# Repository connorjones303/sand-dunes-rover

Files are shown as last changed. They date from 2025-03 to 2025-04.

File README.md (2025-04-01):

# Sand Dunes Rover Project

Spring 2025
Arapahoe Community College Robotics Club - rover project

## Overview

This project implements a rover system designed for sand dune environments. The system consists of:

1. An Arduino-controlled **Rover** with DC motors, servo steering, IMU sensors, and LIDAR
2. A Raspberry Pi **Controller** that interfaces with sensors and communicates with the Arduino

## System Architecture

### Rover Hardware

The rover consists of:

- Arduino controller with SoftPWM for motor control
- 2 DC motor channels for differential drive
- 2 Servo channels for wheel steering
- I2C bus for sensor communication

### Sensor System

The sensor system includes:

- MPU6050 IMU (Accelerometer/Gyroscope) connected via I2C
- LIDAR sensor connected via serial port for distance measurement
- UART connection between Raspberry Pi and Arduino for commands

## Features

- **Movement Control**: Forward, backward, left, right, stop, and active braking
- **Precision Steering**: Servo-controlled wheel direction with configurable angles
- **IMU Data**: Real-time acceleration and gyroscope data collection
- **Motion Detection**: Algorithms to detect significant movement changes
- **LIDAR Scanning**: Collects distance measurements across 360° rotation
- **Data Processing**: Converts LIDAR polar coordinates to Cartesian
- **Data Logging**: Records LIDAR measurements to timestamped files

## Control System

### Arduino Motor Control

- **DC Motor States**:
  - Forward: IN1=HIGH, IN2=LOW
  - Reverse: IN1=LOW, IN2=HIGH
  - Brake: IN1=HIGH, IN2=HIGH
  - Coast: IN1=LOW, IN2=LOW

- **Servo Control**:
  - Straight position: 45 degrees (configurable)
  - Turn margin: 45 degrees (configurable)

### Command Interface

The rover accepts the following UART commands:

- **f**: Move forward
- **b**: Move backward
- **l**: Turn left
- **r**: Turn right
- **s**: Stop motors (coast)
- **t**: Brake motors (active stop)
- **w**: Start writing LIDAR data
- **e**: End writing LIDAR data
- **q**: Quit controller program

## Sensor Details

### MPU6050 IMU Sensor

- Measures acceleration and angular velocity in 3 axes
- Detects movement with configurable thresholds
- Provides data in physical units (g for acceleration, degrees/s for rotation)

### LIDAR Sensor

- Rotational scanner providing 360° distance measurements
- Data provided in polar format (angle, distance, intensity)
- Converts to Cartesian coordinates (x, y)
- Outputs timestamped data for analysis and mapping

## Data Format

### IMU Data Format

```
Accel (g): X=0.00, Y=0.00, Z=0.00 | Gyro (deg/s): X=0.00, Y=0.00, Z=0.00
```
### LIDAR Data Format
```
timestamp,angle,distance,intensity,x,y
1711212151.324,352.45,342,127,328.4,-95.2
```
## Getting Started

### Prerequisites

- Arduino with SoftPWM, Servo, and SoftI2CMaster libraries
- Raspberry Pi with Python 3
- Required Python packages:
  - serial
  - smbus
  - time
  - struct
  - math
  - os
  - datetime

### Hardware Setup

1. Connect Arduino to Raspberry Pi via UART (/dev/ttyACM0)
2. Connect MPU6050 to I2C bus 1
3. Connect LIDAR to serial port (/dev/ttyUSB0)
4. Connect motors and servos as defined in the pin assignments

### Running the Controller

1. Power on the rover hardware
2. Run the Python controller script
3. Enter commands via the terminal interface

## Troubleshooting

### IMU Issues
- Check I2C bus connections
- Verify the IMU address (default: 0x68)
- Use scan_bus() function to detect connected I2C devices

### LIDAR Issues
- Verify serial port connection (/dev/ttyUSB0)
- Ensure baudrate is set to 230400
- Check data format with debug output

### Motor Control Issues
- Verify the Arduino is properly responding to commands
- Check motor driver connections
- Verify servo positions and calibration

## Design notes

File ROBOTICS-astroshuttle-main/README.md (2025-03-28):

# ROBOTICS-astroshuttle

**COSGC ROBOTICS CHALLENGE 2024-2025**  
**TEAM AXIOM @ ARAPAHOE COMMUNITY COLLEGE**  
**ROVR: Oberon**  
**DANIEL KRONEBERGER**

---

## Table of Contents

- [Project Overview](#project-overview)
- [Hardware Components](#hardware-components)
- [Software Components](#software-components)
- [Ultrasonic Navigation System](#ultrasonic-navigation-system)
- [LiDAR System](#lidar-system)
- [Navigation and Control](#navigation-and-control)

---

## Project Overview

**ROVR: Oberon** is an autonomously navigating Martian rover developed for the COSGC Robotics Challenge 2024-2025. Developed with TEAM AXIOM @ ACC.

---

## Hardware Components

- **Motors:**  
  - 4× 25mm gear motors (without encoders)  
  - 2× 20mm gear motors (without encoders)

- **Motor Drivers:**  
  - L298N or BTS7960 motor controllers (depending on availability and performance requirements)

- **Arduino:**  
  - Receives serial commands from the Raspberry Pi and translates them into PWM signals for the motor drivers.  
  - Also manages servo control for steering.

- **Raspberry Pi:**  
  - Runs Ubuntu 22.04 with ROS 2 Humble.  
  - Hosts SLAM and navigation nodes as well as a custom Python command hub that communicates with the Arduino.

- **LD19 LiDAR Module:**  
  - Provides 2D scan data on the `/scan` topic for SLAM mapping and localization.

- **Ultrasonic Sensors:**  
  - Mounted near the wheels, these provide real-time distance measurements to assist in obstacle avoidance and fine navigation adjustments.

- **Additional Components:**  
  - Wiring, power supplies (including boost converters), mounting hardware, and other electronics needed to integrate the system into a mobile robotic platform.

---

## Software Components

- **ROS 2 Humble on Ubuntu 22.04**  
  - Serves as the core middleware for robotic communication and process management.

- **slam_toolbox**  
  - Performs real-time SLAM for mapping and localization in either mapping or localization mode.

- **Nav2 (Navigation 2)**  
  - Plans paths and generates velocity commands on the `/cmd_vel` topic based on user-defined navigation goals.

- **Custom Serial Bridge Node**  
  - Converts ROS velocity commands into serial commands for the Arduino.

- **Arduino Firmware**  
  - Processes a universal serial command protocol to execute commands like `driveF`, `pivotL`, `skidL`, etc.  
  - Controls motors and servos based on these commands.

- **Python Navigation Scripts**  
  - Run on the Raspberry Pi to collect ultrasonic sensor data and autonomously decide optimal navigation commands.  
  - Examples include routines for forward motion followed by pivot scanning to find the best clearance.

---

## Ultrasonic Navigation System

The ultrasonic system enhances local navigation by providing real-time distance measurements:

- **Sensor Setup:**  
  - Two HC-SR04 (or similar) ultrasonic sensors are mounted on the left and right sides of the rover.  
  - Each sensor uses a TRIG and an ECHO pin connected to the Raspberry Pi’s GPIO.

- **Operation:**  
  - The Python script periodically triggers each sensor, calculates the distance based on the echo pulse duration, and evaluates the clearance on both sides.  
  - When the rover is in motion, if either sensor detects an obstacle (or if the combined distance is below a defined threshold), the system initiates a pivot routine.

- **Pivot Routine:**  
  - The rover first drives forward for a preset duration.  
  - It then sequentially pivots left and right (straightening the wheels between movements) to measure the distances at several small angles.  
  - The angle with the greatest combined distance from both sensors is chosen as the optimal heading.  
  - If the distances remain below a threshold, the rover will pivot further to try to clear the obstacle before resuming forward motion.

---

## LiDAR System

The LiDAR system provides a higher-level view of the environment for mapping and navigation:

1. **Mapping Phase:**  
   - The LD19 LiDAR publishes scan data to the `/scan` topic.  
   - `slam_toolbox` processes these scans to generate a 2D map in real time.  
   - The map is visualized in RViz, allowing for immediate feedback during the mapping process.  
   - Once a satisfactory map is generated, it can be saved using the `/slam_toolbox/save_map` service.

2. **Navigation Phase:**  
   - The system is reconfigured to run `slam_toolbox` in localization mode using the saved map.  
   - A navigation goal is set in RViz via the “2D Nav Goal” tool.  
   - Nav2 computes a global path and publishes local velocity commands to `/cmd_vel`.

3. **Motion Execution:**  
   - A custom Serial Bridge Node converts `/cmd_vel` commands into serial commands (such as `driveF` or `pivotL`) that are sent to the Arduino.  
   - The Arduino executes these commands, controlling the motors and servos to move the rover along the planned path.

4. **Optional Odometry Bridge:**  
   - In the absence of wheel encoders, a dummy odometry publisher creates an `/odom` topic from the LiDAR-based pose estimate, ensuring compatibility with Nav2’s requirements.

---

## Navigation and Control

The rover’s navigation system is a combination of high-level planning and low-level sensor-based adjustments:

- **Universal Serial Command Protocol:**  
  A standard set of commands has been defined to control the rover’s movements:

  - `skidL` – skid steer left (in-place turn) [DC only]  
  - `skidR` – skid steer right (in-place turn) [DC only]  
  - `driveF` – drive forward  
  - `driveB` – drive backward  
  - `driveL` – servo-assisted turn left (no differential drive)  
  - `driveR` – servo-assisted turn right (no differential drive)  
  - `DdriveL` – servo-assisted turn left (with slight differential drive)  
  - `DriveR` – servo-assisted turn right (with slight differential drive)  
  - `pivotL` – turns servos into a circle and skids left  
  - `pivotR` – turns servos into a circle and skids right  
  - `steerL` – servo ONLY turn left (no drive)  
  - `steerR` – servo ONLY turn right (no drive)  
  - `steerZ` – zero the servos  
  - `S` – stop motors  
  - `C` – show commands

- **Raspberry Pi Command Hub:**  
  - A Python application running on the Pi communicates with the Arduino over serial.  
  - It reads ultrasonic sensor data via the GPIO pins.  
  - Based on sensor input, it determines whether to drive forward or perform a pivot scan.  
  - The system tests multiple pivot angles (with wheel straightening between each pivot) and selects the angle that yields the maximum clearance.  
  - The chosen command is then sent to the Arduino to execute the movement.

---

*For any questions or contributions, please contact Daniel Kroneberger or open an issue on this repository.*

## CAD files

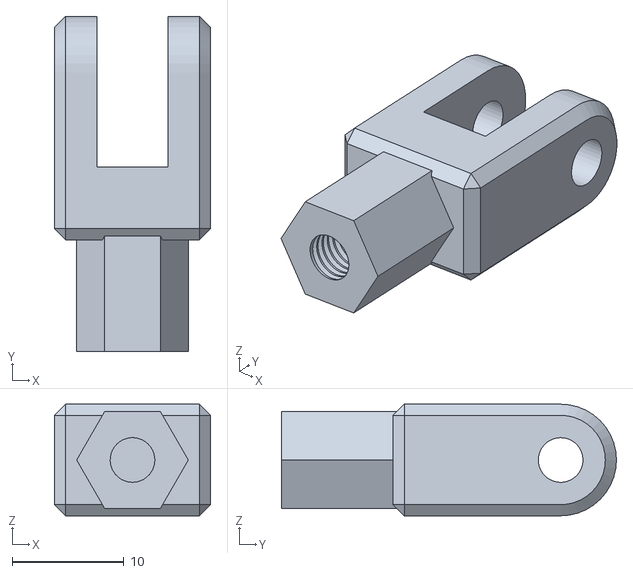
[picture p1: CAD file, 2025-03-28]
ROBOTICS-astroshuttle-main/STLs-astroshuttle/BLUEpart-astroshuttle.STL
14.0 x 30.0 x 10.0

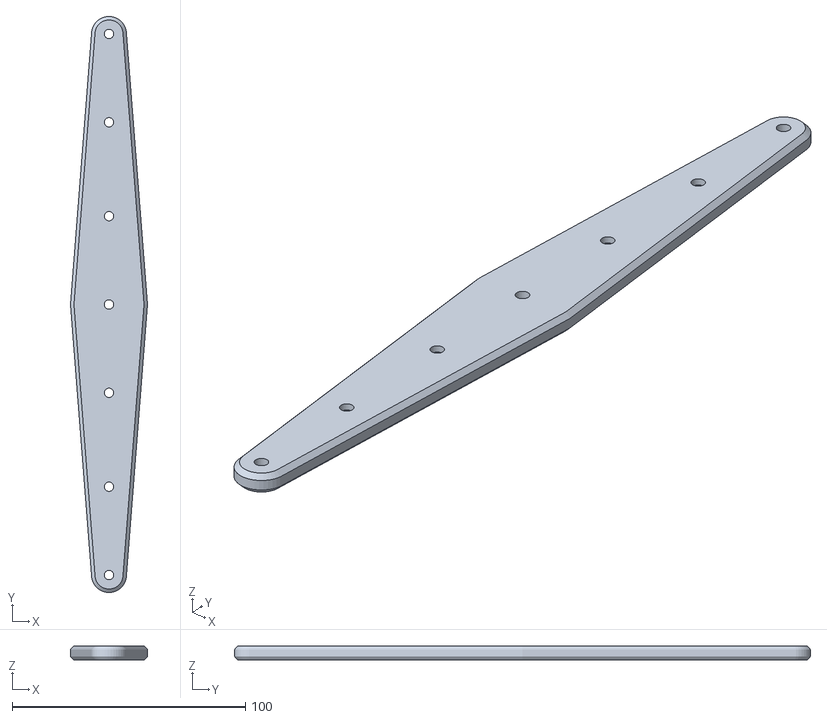
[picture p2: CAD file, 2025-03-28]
ROBOTICS-astroshuttle-main/STLs-astroshuttle/purplebar-astroshuttle.STL
33.0 x 247.0 x 6.00

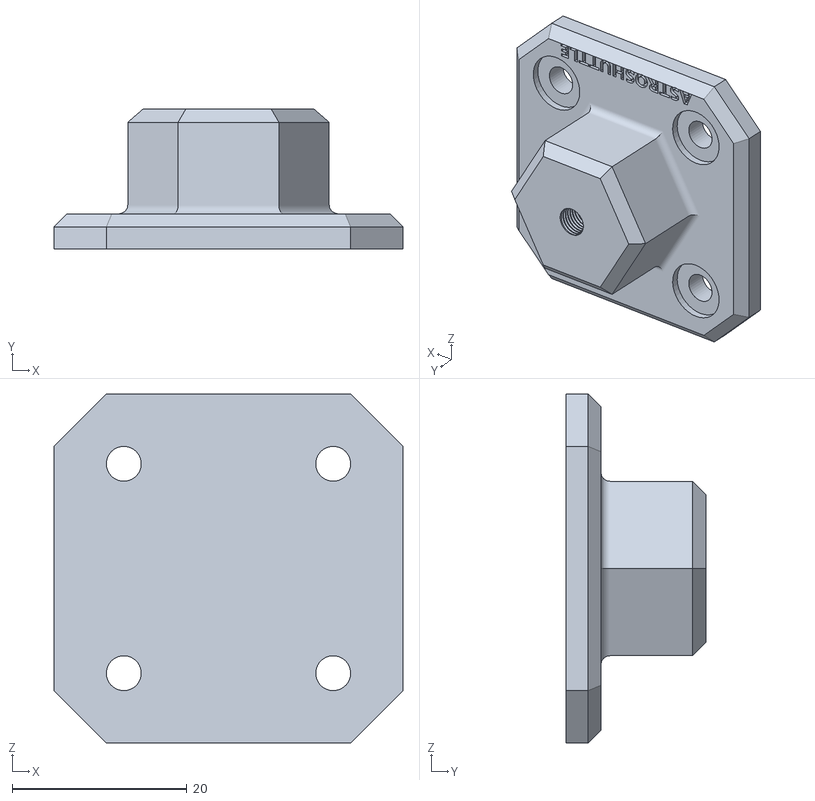
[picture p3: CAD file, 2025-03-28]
ROBOTICS-astroshuttle-main/STLs-astroshuttle/REDpartEVEN-astroshuttle.STL
40.0 x 16.0 x 40.0

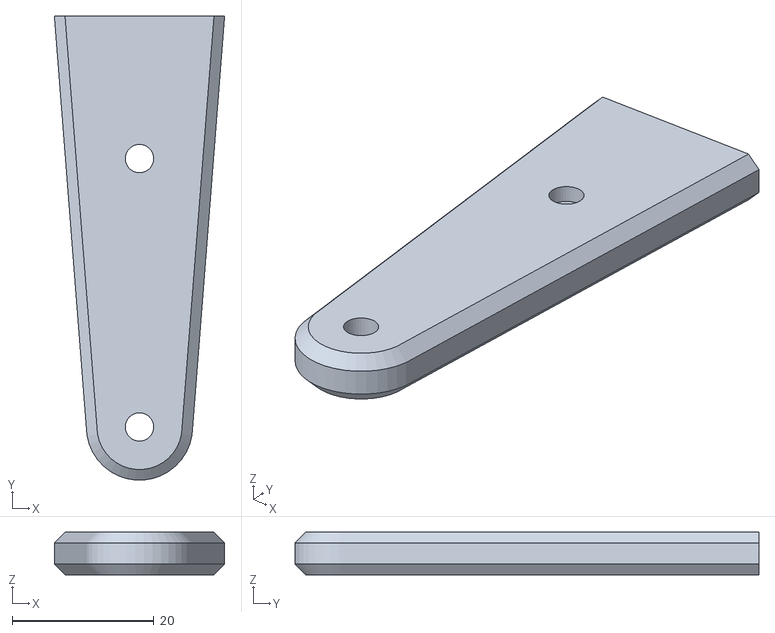
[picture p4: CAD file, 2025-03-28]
ROBOTICS-astroshuttle-main/STLs-astroshuttle/purplebar-edge-astroshuttle.STL
24.0 x 65.5 x 6.00

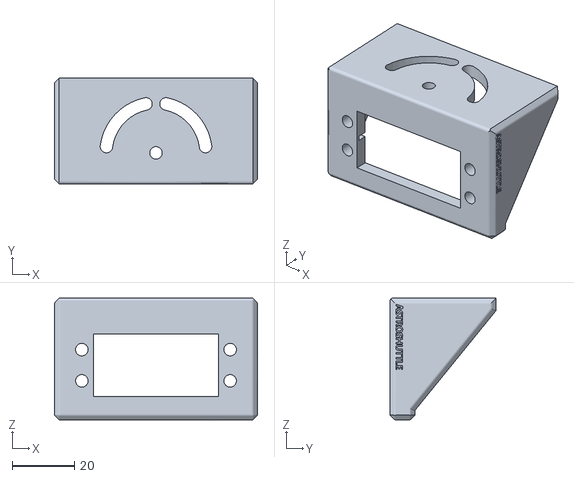
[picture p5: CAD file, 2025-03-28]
ROBOTICS-astroshuttle-main/STLs-astroshuttle/ServoHousing-astroshuttle.STL
65.0 x 34.0 x 39.0

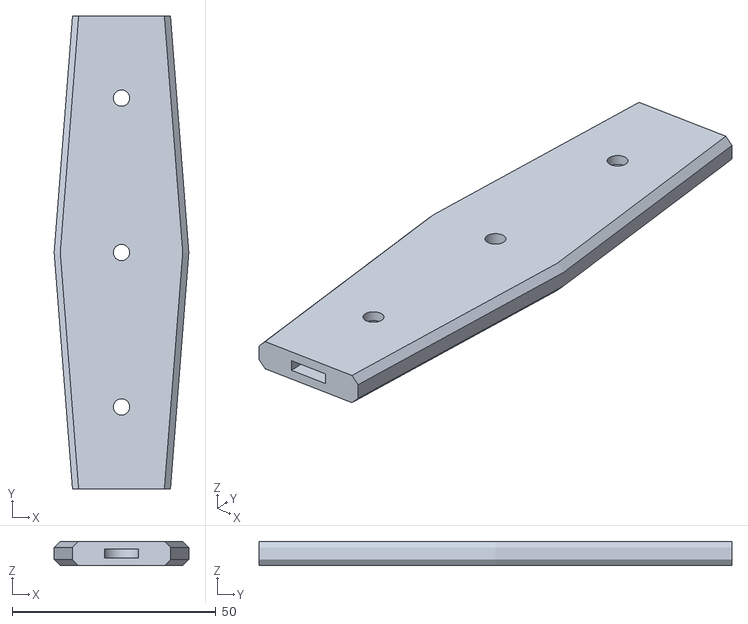
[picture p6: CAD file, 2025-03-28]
ROBOTICS-astroshuttle-main/STLs-astroshuttle/purplebar-center.STL
33.0 x 116.0 x 6.00

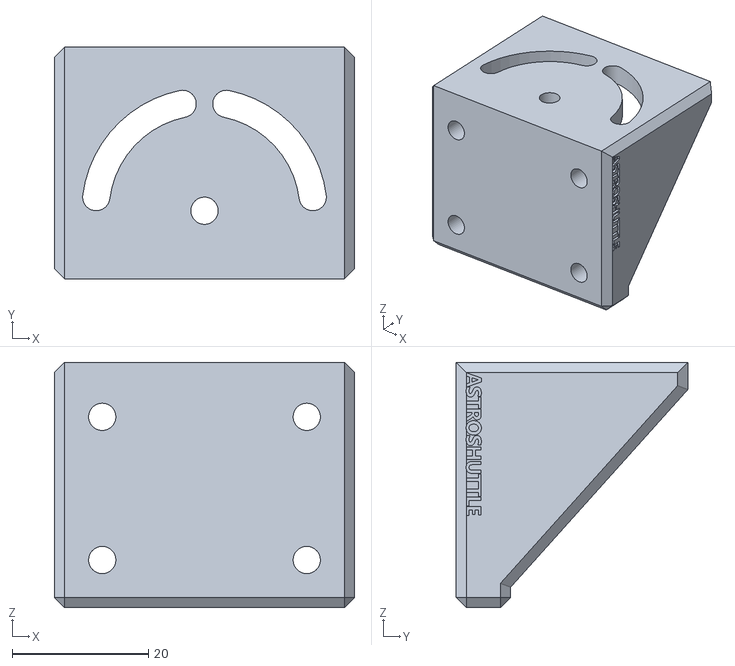
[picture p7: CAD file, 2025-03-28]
ROBOTICS-astroshuttle-main/STLs-astroshuttle/middleDCMotorHousing-top-astroshuttle.STL
44.0 x 34.0 x 36.0

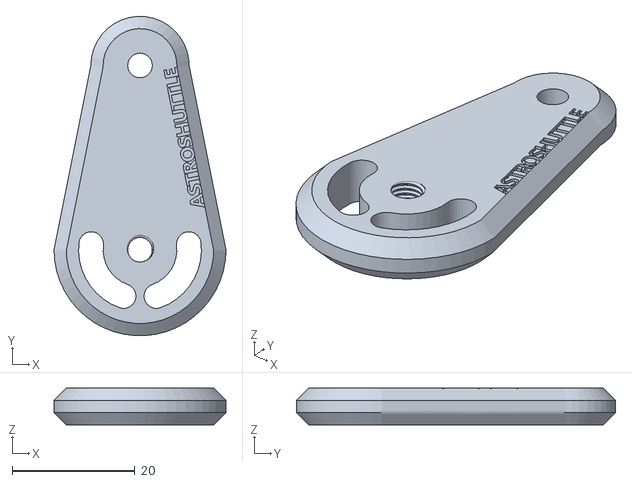
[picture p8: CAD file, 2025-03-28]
ROBOTICS-astroshuttle-main/STLs-astroshuttle/GREENpart-astroshuttle.STL
28.0 x 52.0 x 6.00

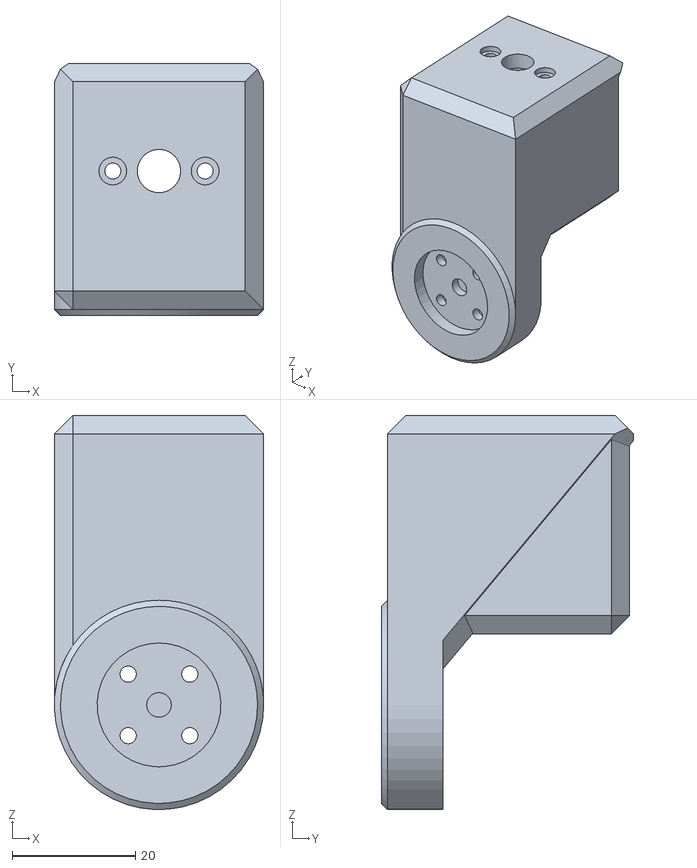
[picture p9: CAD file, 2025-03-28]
ROBOTICS-astroshuttle-main/STLs-astroshuttle/DCMotorHousingECON-astroshuttle.STL
34.0 x 41.0 x 64.0

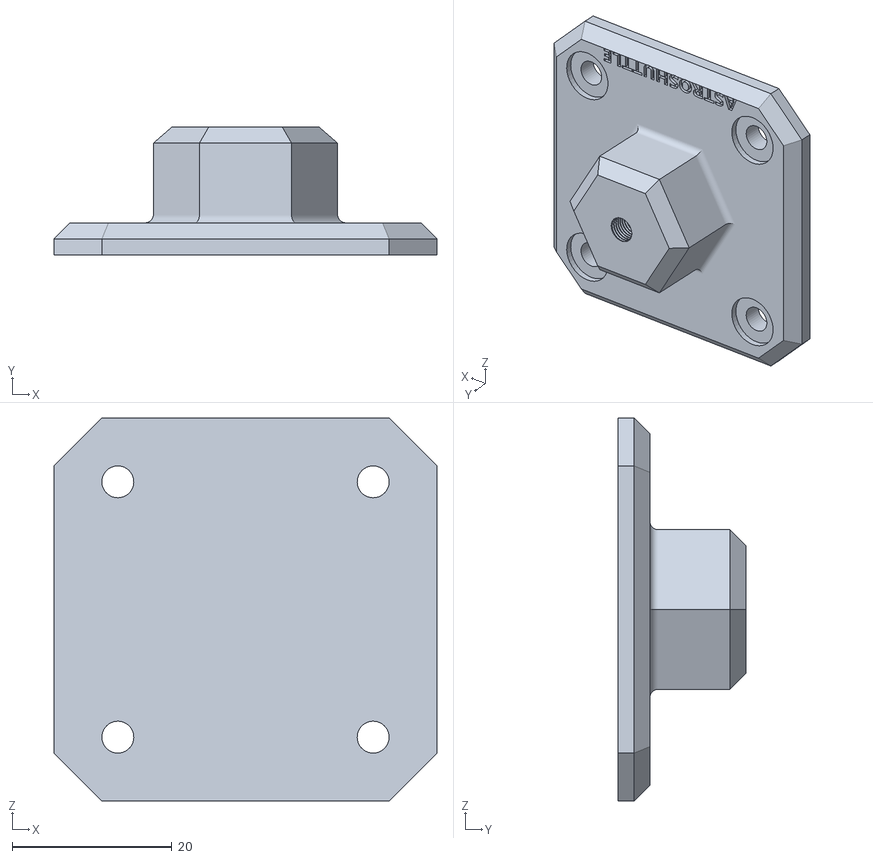
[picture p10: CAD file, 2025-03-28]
ROBOTICS-astroshuttle-main/STLs-astroshuttle/REDpartODD-astroshuttle.STL
48.0 x 16.0 x 48.0

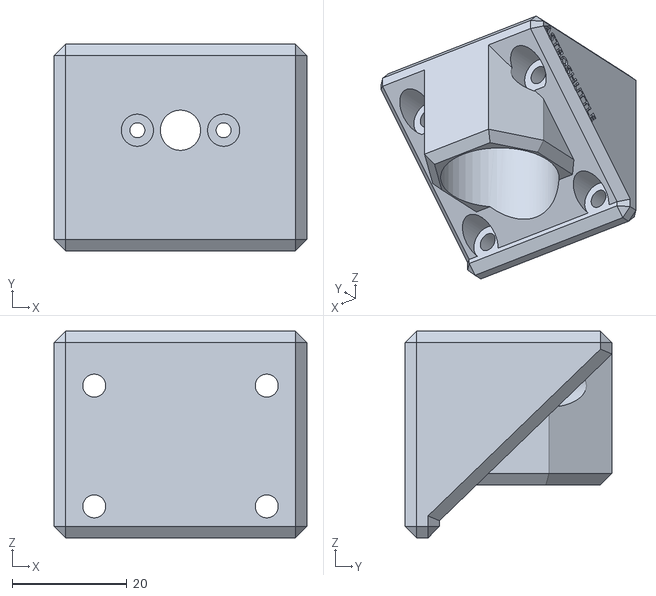
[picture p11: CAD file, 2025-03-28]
ROBOTICS-astroshuttle-main/STLs-astroshuttle/middleDCMotorHousingECON-bottom-astroshuttle.STL
44.0 x 36.0 x 36.0

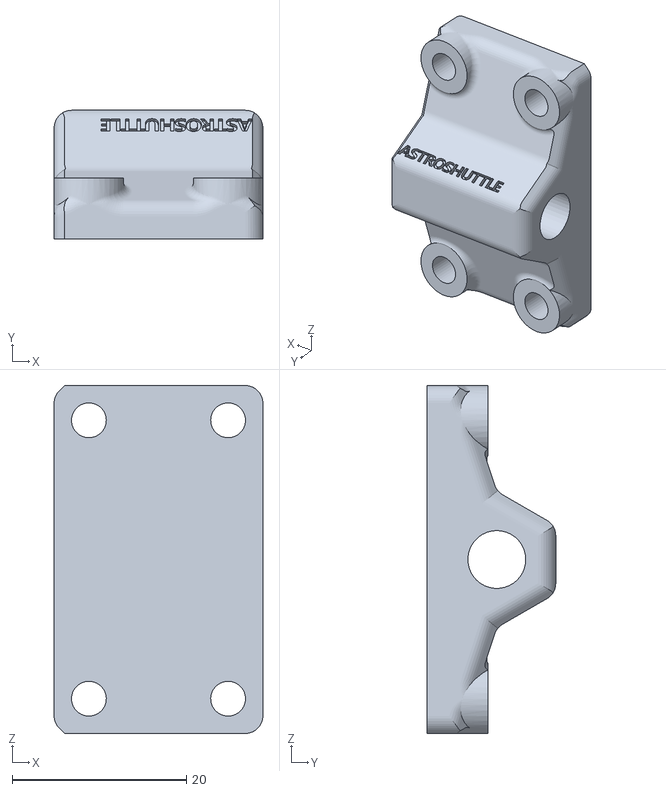
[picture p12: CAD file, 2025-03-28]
ROBOTICS-astroshuttle-main/STLs-astroshuttle/axleHousing-astroshuttle.STL
24.0 x 14.8 x 40.0

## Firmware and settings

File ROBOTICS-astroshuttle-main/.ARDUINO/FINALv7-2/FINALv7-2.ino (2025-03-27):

#include <Servo.h>
#include <SoftPWM.h>

// ••••••••••••••••••••••••••• DC MOTOR PINS •••••••••••••••••••••••••••
// DC MOTOR - LEFT side
const int LEFT_MOTOR_B_PIN = 6;  // forward channel
const int LEFT_MOTOR_F_PIN = 9;  // reverse channel
// DC MOTOR - RIGHT side
const int RIGHT_MOTOR_B_PIN = 5; // forward channel
const int RIGHT_MOTOR_F_PIN = 3; // reverse channel

// ••••••••••••••••••••••••••• SPEEDS(0–255) •••••••••••••••••••••••••••
const int DEFAULT_SPEED = 160; 
const int TURN_SPEED    = 160;  

// ••••••••••••••••••••••••••• SERVO PINS •••••••••••••••••••••••••••
// Channel A: fR + bL
// Channel B: fL + bR
const int SERVO_FR_PIN = 11;  // fR
const int SERVO_FL_PIN = 10;  // fL
const int SERVO_BL_PIN = 12;  // bL
const int SERVO_BR_PIN = 13;  // bR

// ••••••••••••••••••••••••••• SERVO ANGLES •••••••••••••••••••••••••••
const int SERVO_CENTER       = 90;  // all servos centered when straight
const int SERVO_TURN_ANGLE   = 30;  // standard turn offset for non-pivot commands
const int PIVOT_SERVO_OFFSET = 30;  // offset for pivoting (wheels turn inward)

// ••••••••••••••••••••••••••• SERVO OBJECTS •••••••••••••••••••••••••••
Servo servoA1; // Front Right (Channel A)
Servo servoA2; // Back Left (Channel A)
Servo servoB1; // Front Left (Channel B)
Servo servoB2; // Back Right (Channel B)

// ••••••••••••••••••••••••••••••••••••••••••••••••••••••
//                       SETUP
// ••••••••••••••••••••••••••••••••••••••••••••••••••••••
void setup() {
  Serial.begin(9600);
  pinMode(LEFT_MOTOR_F_PIN, OUTPUT);
  pinMode(LEFT_MOTOR_B_PIN, OUTPUT);
  pinMode(RIGHT_MOTOR_F_PIN, OUTPUT);
  pinMode(RIGHT_MOTOR_B_PIN, OUTPUT);
  SoftPWMBegin();
  softPwmCreate(LEFT_MOTOR_F_PIN, 0, 255);
  softPwmCreate(LEFT_MOTOR_B_PIN, 0, 255);
  softPwmCreate(RIGHT_MOTOR_F_PIN, 0, 255);
  softPwmCreate(RIGHT_MOTOR_B_PIN, 0, 255);
  servoA1.attach(SERVO_FR_PIN);
  servoB1.attach(SERVO_FL_PIN);
  servoA2.attach(SERVO_BL_PIN);
  servoB2.attach(SERVO_BR_PIN);
  
  steerZ();
  stopMotors();
  
  Serial.println("•••••••••••••••••••••••••••••••••••••••••••••••••••••••••••••••••••••••••••••••••••••••••••••••••••••");
  Serial.println("•                                       Oberon INITIALIZED                                          •");
  Serial.println("•••••••••••••••••••••••••••••••••••••••••••••••••••••••••••••••••••••••••••••••••••••••••••••••••••••");
  Serial.println("•                                                                                                   •");
  Serial.println("•    skidL, skidR, driveF, driveB, driveL, driveR, DdriveL, DriveR, pivotL, pivotR, steerL, steerR, steerZ, S   •");
  Serial.println("•                                                                                                   •");
  Serial.println("•••••••••••••••••••••••••••••••••••••••••••••••••••••••••••••••••••••••••••••••••••••••••••••••••••••");
  Serial.println(" 'C' to show these commands again ");
}

// ••••••••••••••••••••••••••••••••••••••••••••••••••••••
//                   MAIN PROGRAM LOOP
// ••••••••••••••••••••••••••••••••••••••••••••••••••••••
void loop() {
  if (Serial.available() > 0) {
    String command = Serial.readStringUntil('\n');
    command.trim();
    
    if (command == "skidL") {
      skidL();
    } else if (command == "skidR") {
      skidR();
    } else if (command == "driveF") {
      driveF();
    } else if (command == "driveB") {
      driveB();
    } else if (command == "driveL") {
      driveL();
    } else if (command == "driveR") {
      driveR();
    } else if (command == "DdriveL") {
      DdriveL();
    } else if (command == "DriveR") {
      DriveR();
    } else if (command == "pivotL") {
      pivotL();
    } else if (command == "pivotR") {
      pivotR();
    } else if (command == "steerL") {
      steerL();
    } else if (command == "steerR") {
      steerR();
    } else if (command == "steerZ") {
      steerZ();
    } else if (command == "S") {
      stopMotors();
    } else if (command == "C") {
      showCommands();
    } else {
      Serial.print("Unknown command: ");
      Serial.println(command);
    }
    
    Serial.print("Executed command: ");
    Serial.println(command);
  }
}
void showCommands() {
  Serial.println("•••••••••••••••••••••••••••••••••••••••••••••••••••••••••••••••••••••••••••••••••••••••••••");
  Serial.println("•    skidL, skidR, driveF, driveB, driveL, driveR, DdriveL, DriveR, pivotL, pivotR, steerL, steerR, steerZ, S, C    •");
  Serial.println("•••••••••••••••••••••••••••••••••••••••••••••••••••••••••••••••••••••••••••••••••••••••••••");
}
// ••••••••••••••••••••••••••••••••••••••••••••••••••••••
//              MOTOR CONTROL FUNCTIONS
// ••••••••••••••••••••••••••••••••••••••••••••••••••••••
void stopMotors() {
  softPwmWrite(LEFT_MOTOR_F_PIN, 0);
  softPwmWrite(LEFT_MOTOR_B_PIN, 0);
  softPwmWrite(RIGHT_MOTOR_F_PIN, 0);
  softPwmWrite(RIGHT_MOTOR_B_PIN, 0);
}

void driveF() {
  softPwmWrite(LEFT_MOTOR_F_PIN, DEFAULT_SPEED);
  softPwmWrite(LEFT_MOTOR_B_PIN, 0);
  softPwmWrite(RIGHT_MOTOR_F_PIN, DEFAULT_SPEED);
  softPwmWrite(RIGHT_MOTOR_B_PIN, 0);
}

void driveB() {
  softPwmWrite(LEFT_MOTOR_F_PIN, 0);
  softPwmWrite(LEFT_MOTOR_B_PIN, DEFAULT_SPEED);
  softPwmWrite(RIGHT_MOTOR_F_PIN, 0);
  softPwmWrite(RIGHT_MOTOR_B_PIN, DEFAULT_SPEED);
}

void skidL() {
  softPwmWrite(LEFT_MOTOR_F_PIN, 0);
  softPwmWrite(LEFT_MOTOR_B_PIN, TURN_SPEED);
  softPwmWrite(RIGHT_MOTOR_F_PIN, TURN_SPEED);
  softPwmWrite(RIGHT_MOTOR_B_PIN, 0);
}

void skidR() {
  softPwmWrite(LEFT_MOTOR_F_PIN, TURN_SPEED);
  softPwmWrite(LEFT_MOTOR_B_PIN, 0);
  softPwmWrite(RIGHT_MOTOR_F_PIN, 0);
  softPwmWrite(RIGHT_MOTOR_B_PIN, TURN_SPEED);
}

// *********************************************************
//             DC + SERVO FUNCTIONS
// *********************************************************
void driveL() {
  steerL();
  driveF();
}

void driveR() {
  steerR();
  driveF();
}

void DdriveL() {
  steerL();
  softPwmWrite(LEFT_MOTOR_F_PIN, SLOW_SPEED);
  softPwmWrite(LEFT_MOTOR_B_PIN, 0);
  softPwmWrite(RIGHT_MOTOR_F_PIN, DEFAULT_SPEED);
  softPwmWrite(RIGHT_MOTOR_B_PIN, 0);
}

void DriveR() {
  steerR();
  softPwmWrite(LEFT_MOTOR_F_PIN, DEFAULT_SPEED);
  softPwmWrite(LEFT_MOTOR_B_PIN, 0);
  softPwmWrite(RIGHT_MOTOR_F_PIN, SLOW_SPEED);
  softPwmWrite(RIGHT_MOTOR_B_PIN, 0);
}

// ••••••••••••••••••••••••••••••••••••••••••••••••••••••
//                  PIVOT FUNCTIONS
// ••••••••••••••••••••••••••••••••••••••••••••••••••••••
void pivotL() {
  // For pivot left: make servos point inward
  // Channel A (FR & BL) turn left; Channel B (FL & BR) turn right
  servoA1.write(SERVO_CENTER - PIVOT_SERVO_OFFSET);
  servoA2.write(SERVO_CENTER - PIVOT_SERVO_OFFSET);
  servoB1.write(SERVO_CENTER + PIVOT_SERVO_OFFSET);
  servoB2.write(SERVO_CENTER + PIVOT_SERVO_OFFSET);
  
  // Skid-style pivot: left motors reverse, right motors forward
  softPwmWrite(LEFT_MOTOR_F_PIN, 0);
  softPwmWrite(LEFT_MOTOR_B_PIN, TURN_SPEED);
  softPwmWrite(RIGHT_MOTOR_F_PIN, TURN_SPEED);
  softPwmWrite(RIGHT_MOTOR_B_PIN, 0);
}

void pivotR() {
  // For pivot right: make servos point inward in opposite direction
  // Channel A (FR & BL) turn right; Channel B (FL & BR) turn left
  servoA1.write(SERVO_CENTER + PIVOT_SERVO_OFFSET);
  servoA2.write(SERVO_CENTER + PIVOT_SERVO_OFFSET);
  servoB1.write(SERVO_CENTER - PIVOT_SERVO_OFFSET);
  servoB2.write(SERVO_CENTER - PIVOT_SERVO_OFFSET);
  
  // Skid-style pivot: left motors forward, right motors reverse
  softPwmWrite(LEFT_MOTOR_F_PIN, TURN_SPEED);
  softPwmWrite(LEFT_MOTOR_B_PIN, 0);
  softPwmWrite(RIGHT_MOTOR_F_PIN, 0);
  softPwmWrite(RIGHT_MOTOR_B_PIN, TURN_SPEED);
}

// ••••••••••••••••••••••••••••••••••••••••••••••••••••••
//              SERVO CONTROL FUNCTIONS
// ••••••••••••••••••••••••••••••••••••••••••••••••••••••
void steerL() {
  servoA1.write(SERVO_CENTER - SERVO_TURN_ANGLE);
  servoA2.write(SERVO_CENTER - SERVO_TURN_ANGLE);
  servoB1.write(SERVO_CENTER + SERVO_TURN_ANGLE);
  servoB2.write(SERVO_CENTER + SERVO_TURN_ANGLE);
}

void steerR() {
  servoA1.write(SERVO_CENTER + SERVO_TURN_ANGLE);
  servoA2.write(SERVO_CENTER + SERVO_TURN_ANGLE);
  servoB1.write(SERVO_CENTER - SERVO_TURN_ANGLE);
  servoB2.write(SERVO_CENTER - SERVO_TURN_ANGLE);
}

void steerZ() {
  servoA1.write(SERVO_CENTER);
  servoA2.write(SERVO_CENTER);
  servoB1.write(SERVO_CENTER);
  servoB2.write(SERVO_CENTER);
}

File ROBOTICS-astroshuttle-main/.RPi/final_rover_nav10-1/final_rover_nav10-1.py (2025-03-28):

#THIS PROGRAM [final_nav_roverv9-1] IS A COMBINATION OF dspv8-3 AND nav_roverv7-6

import RPi.GPIO as GPIO
import time
import serial
import smbus
import math
############################################################
"""
MAIN LOOP 
    1 drive forward
    2 deploy an ultrasonic scan
    3 pivot to best angle based on sweep
    4 set target heading from compass and drive straight using heading correction
    5 loop 
"""
############################################################
"""
servo_sweep_scan:

    - sweep by moving the sensors incrementally left and right
    
    - record both distance measurements at each step
    
    - center and evaluate which angle (measured in steps from center)
    
    - calculates the best reading (high combined distance and balanced left/right values)
    
    Returns:
        best_angle (int): negative for left, positive for right, 0 for center.
"""
############################################################
"""
COMPASS FUNCTIONS:

    - init_compass: initializes the HMC5883L magnetometer
    - read_compass_data: reads a 16-bit value from the compass
    - get_compass_heading: returns the current heading in degrees (0-360)
"""
############################################################

# GPIO PINS for ULTRASONIC
TRIG_LEFT = 17
ECHO_LEFT = 27
TRIG_RIGHT = 22
ECHO_RIGHT = 23

# SERIAL INFO
SERIAL_PORT = '/dev/ttyUSB0'  # may change with lidar, etc.
BAUD_RATE = 9600

# DISTANCE THRESHOLD (for deciding if path is “clear”)
CLEAR_DISTANCE = 25.0

# Sweep increments: more steps = finer search, but slower
PIVOT_STEPS = 12 

# CONSTANTS FOR SCORING
MAX_OFFSET = 10.0       # maximum acceptable difference (cm) between left & right readings
PENALTY_FACTOR = 1.0    # penalty for imbalance (per cm difference)

# CUSTOM VARIABLES for drive-straight
STEERING_TIME = 0.4     # base steering time (to be scaled)
HEADING_THRESHOLD = 5.0 # threshold (degrees) for heading correction

# COMPASS SETTINGS
COMPASS_ADDRESS = 0x1E

# INITIALIZE GPIO
GPIO.setmode(GPIO.BCM)
GPIO.setwarnings(False)
GPIO.setup(TRIG_LEFT, GPIO.OUT)
GPIO.setup(ECHO_LEFT, GPIO.IN)
GPIO.setup(TRIG_RIGHT, GPIO.OUT)
GPIO.setup(ECHO_RIGHT, GPIO.IN)

# INITIALIZE SERIAL
try:
    ser = serial.Serial(SERIAL_PORT, BAUD_RATE, timeout=1)
    time.sleep(2) 
    print(f"Serial connection established on {SERIAL_PORT}")
except Exception as e:
    print("Failed to open serial port:", e)
    exit()

# INITIALIZE I2C (for both compass and any other I2C sensors)
bus = smbus.SMBus(1)

############################################################
#                     COMPASS FUNCTIONS                  #
############################################################

def init_compass():
    # Configuration Register A: 8-average, 15 Hz, normal measurement
    bus.write_byte_data(COMPASS_ADDRESS, 0x00, 0x70)
    # Configuration Register B: Gain = 5
    bus.write_byte_data(COMPASS_ADDRESS, 0x01, 0xA0)
    # Mode Register: Continuous measurement mode
    bus.write_byte_data(COMPASS_ADDRESS, 0x02, 0x00)
    time.sleep(0.1)
    print("Compass initialized.")

def read_compass_data(addr):
    high = bus.read_byte_data(COMPASS_ADDRESS, addr)
    low = bus.read_byte_data(COMPASS_ADDRESS, addr+1)
    value = (high << 8) | low
    if value > 32767:
        value = value - 65536
    return value

def get_compass_heading():
    x = read_compass_data(0x03)
    z = read_compass_data(0x05)
    y = read_compass_data(0x07)
    heading_rad = math.atan2(y, x)
    if heading_rad < 0:
        heading_rad += 2 * math.pi
    heading_deg = math.degrees(heading_rad)
    return heading_deg

def heading_difference(current, target):
    diff = current - target
    while diff < -180:
        diff += 360
    while diff > 180:
        diff -= 360
    return diff

############################################################
#                   ULTRASONIC FUNCTIONS                   #
############################################################

def send_command(command):
    cmd = command.strip() + "\n"
    ser.write(cmd.encode('utf-8'))
    print("Sent:", command)

def read_response():
    while ser.in_waiting:
        line = ser.readline().decode('utf-8').strip()
        if line:
            print("Arduino:", line)

def measure_distance(trig_pin, echo_pin):
    GPIO.output(trig_pin, False)
    time.sleep(0.0002)
    GPIO.output(trig_pin, True)
    time.sleep(0.00001)
    GPIO.output(trig_pin, False)

    start_time = time.time()
    timeout = start_time + 0.04 
    while GPIO.input(echo_pin) == 0:
        start_time = time.time()
        if start_time > timeout:
            return None

    end_time = time.time()
    timeout = end_time + 0.04
    while GPIO.input(echo_pin) == 1:
        end_time = time.time()
        if end_time > timeout:
            return None

    pulse_duration = end_time - start_time
    distance = pulse_duration * 34300 / 2.0
    return distance

def get_ultrasonic_distances():
    left = measure_distance(TRIG_LEFT, ECHO_LEFT)
    right = measure_distance(TRIG_RIGHT, ECHO_RIGHT)
    return (left, right)

def path_is_clear(left_dist, right_dist, threshold=CLEAR_DISTANCE):
    if left_dist is None or right_dist is None:
        return False
    return (left_dist > threshold and right_dist > threshold)
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

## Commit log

2025-03-25 changed main.py for robot to include commands to start lidar recording
2025-03-25 changed main.oy again for lidar test recording while driving
2025-03-25 modifying main.py to work with lidar commands
2025-03-26 Add files via upload
    - rewrote in the SoftPWM library so we can have a bit more control over our servo
    - included new pivot functions
2025-03-27 added python code so zach can run two wheel
2025-03-28 adding daniel's repo
    [BLUEpart-astroshuttle.STL, DCMotorHousingECON-astroshuttle.STL, GREENpart-astroshuttle.STL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]
2025-03-28 integrated imu with main robot program
2025-03-28 added function to detect signifcant change in gyro/accel
2025-03-28 fixed method error in significant change function inside MPU6050 class
    [imu.py, main.py]
2025-03-28 print fix in main.py to see significant change funciton return value
    [main.py]
